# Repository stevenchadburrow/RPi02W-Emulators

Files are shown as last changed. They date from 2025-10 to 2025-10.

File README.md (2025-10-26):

# RPi02W-Emulators
<b>Running Emulators on a Raspberry Pi Zero 2W</b><br>

<b>Purpose:</b><br>
This project is to introduce myself to how the Raspberry Pi Zero 2W works, and further my knowledge on 'modern' microprocessors running Linux.  The immediate goal is to make a handheld device that plays NES, Gameboy, Gameboy Color, and Gameboy Advance games that can also connect to the television.  Additional emulators to follow.<br>

<b>Connecting an ILI9341 LCD in SPI mode using pins:</b><br>
CS = GPIO8 / Pin24<br>
MISO = GPIO9 / Pin21<br>
MOSI = GPIO10 / Pin19<br>
SCLK = GPIO11 / Pin23<br>
RESET = GPIO0 / Pin27<br>
DC = GPIO1 / Pin28<br>
LED is connected to 3V3<br>

<b>Connecting a 3.5mm Audio Jack using pins:</b><br>
LEFT = GPIO12 / Pin32<br>
RIGHT = GPIO13 / Pin33<br>

<b>Additional Requirements:</b><br>
You will also need a USB-Micro to USB-A (Female) adapter, and an HDMI-mini to HDMI adapter.<br>

<b>Instructions to Install:</b><br>
1) Re-image an 8GB+ SD Card with Raspberry Pi OS (Lite) 64-bit.<br>
2) Create user named ``` username ``` with pass named ``` password ```.<br>
3) ``` sudo raspi-config ```, change settings in Auto Login to automatically login without password required, as well as booting to Console instead of Desktop.<br>
4) ``` mkdir ~/Emulators ```, put all files found here into that folder.<br>
5) ``` mkdir ~/Emulators/ROMS ```, put whatever ROMs into that folder.  You can use sub-folders to help organize your ROMs.<br>
6) You can pull the SD Card from the Pi and connect it to another Linux computer to transfer files, use built-in Desktop environment, or some other means.<br>
7) ``` sudo nano /boot/firmware/config.txt ```, and comment out the line ``` #dtoverlay=vc4-kms-v3d ```, the then add these lines to the bottom under ``` [all] ```:
   ```
   dtoverlay=vc4-fkms-v3d
   hdmi_group=1
   hdmi_mode=1
   hdmi_drive=2
   max_framebuffers=2
   enable_tvout=0
   dtparam=spi=on
   dtoverlay=fbtft,spi0-0,ili9341,bgr,rotate=270,speed=50000000,dc_pin=1,reset_pin=0,framebuffer_width=320,framebuffer_height=240
   dtoverlay=audremap,pins_12_13
   audio_pwm_mode=2
   disable_audio_dither
   ```
8) Optionally you can also overclock the Pi by also including:
   ```
   arm_freq=1200
   over_voltage=2
   ```
9) ``` sudo nano /boot/firmware/cmdline.txt ```, then add to the end of the first line:
   ```
   video=HDMI-A-1:640x480M@60,margin_top=20,margin_bottom=20,margin_left=20,margin_right=20
   ```
10) ``` sudo nano /etc/rc.local ```, and if file already exists, just add ``` sudo modprobe snd-pcm-oss ```.  Else, add these lines to the file:
    ```
    #!/bin/sh
    sudo modprobe snd-pcm-oss
    exit 0
    ```
11) ``` sudo chmod +rwx /etc/rc.local ; sudo chown root /etc/rc.local ``` to give permissions to file.<br>
12) ``` sudo reboot ``` for changes to take effect.<br>
13) ``` cd ~/Emulators ; sh install.sh ```, to compile all C files.<br>
14) To run: ``` cd ~/Emulators ; sh run.sh ```, or to auto run on boot: ``` echo 'cd ~/Emulators/ ; sh run.sh' >> ~/.bashrc ```.<br>

<b>Features:</b><br>
- If HDMI is plugged in on boot, games will be played through HDMI.  Else, games will be played through LCD.<br>
- It can use the on-board buttons, a USB keyboard, or an Xbox360 style USB controller.<br>
- Has additional features such as fast-forward button, turbo buttons, and save/load RAM to external file.<br>
- All files here are compiled using ``` gcc ``` and only uses standard Linux libraries.<br>
- In order to draw to the screen, each emulator will write directly to ``` /dev/fb0 ```.<br>
- In order to get on-board button state, each emulator will read directly from GPIO pins using the ``` pigpio ``` library.<br>
- In order to get keyboard events, each emulator will read directly from ``` /dev/input/event0 ```.<br>
- In order to get joystick events, each emulator will read directly from ``` /dev/input/js0 ```.<br>
- In order to send audio data, each emulator will stream directly to ``` /dev/dsp ```.<br>
- Warning: ``` /dev/dsp ``` is only available after ``` sudo modprobe snd-pcm-oss ```.<br>

<b>NES, GB, and GBA Emulator Development:</b><br>
- PICnes is my own NES emulator that was previously made for the PIC32MZ, initial code found <a href="https://github.com/stevenchadburrow/AcolyteHandheld">here</a>.<br>
- PeanutGB is an MIT licensed GB/GBC emulator, found <a href="https://github.com/deltabeard/Peanut-GB">here</a>. The PeanutGB emulator used is actually a version by 'froggestspirit', found <a href="https://github.com/froggestspirit/Peanut-GB">here</a>, in order to play Gameboy Color games.<br>
- gdkGBA is a public domain GBA emulator, found <a href="https://github.com/gdkchan/gdkGBA">here</a>.  I have been altering it by copying code from a version by 'jakibaki', found <a href="https://github.com/jakibaki/gdkGBA">here</a>.  It runs well enough at 20 FPS.  I'm using Normmatt's open-source BIOS, hosted by Nebuleon <a href="https://github.com/Nebuleon/ReGBA/">here</a>.<br>

<b>Videos:</b><br>
<a href="https://youtube.com/shorts/ARCSKjPH7FA?si=rqlXaKl9zKCdxzBo">Youtube Short of me playing Tobu Tobu Girl DX</a><br>

<b>Pictures:</b><br>
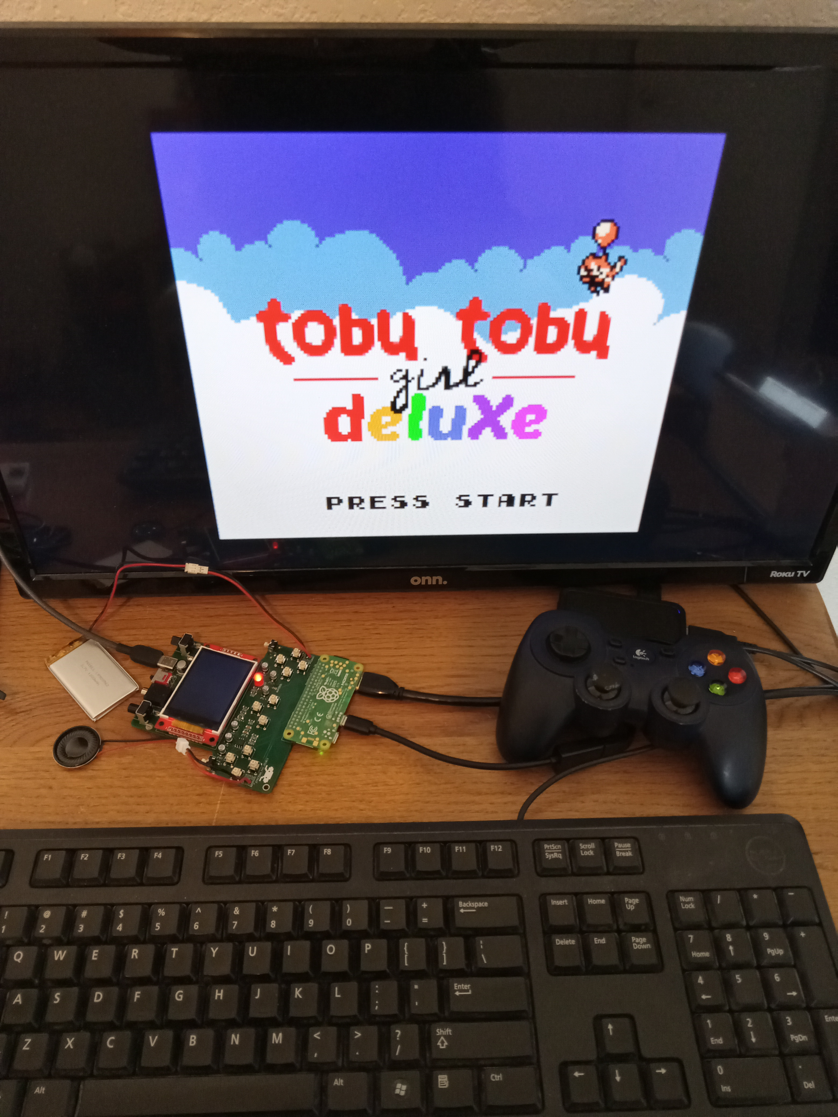
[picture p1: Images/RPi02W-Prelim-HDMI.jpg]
<br>
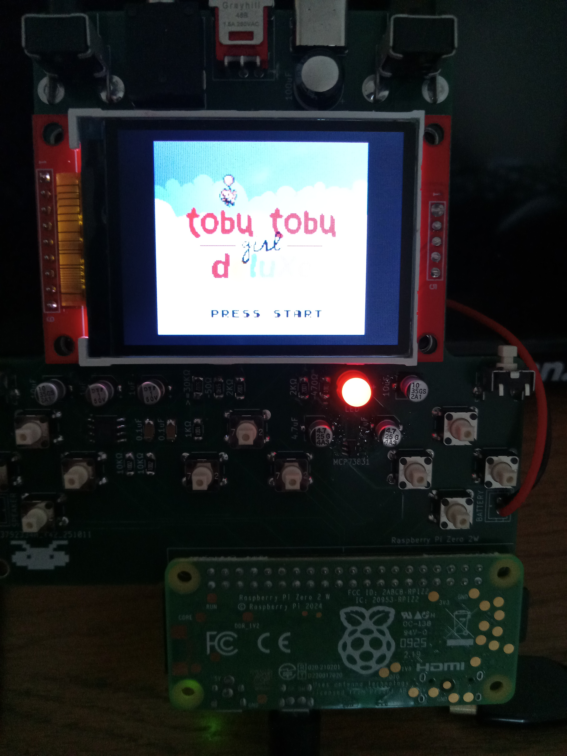
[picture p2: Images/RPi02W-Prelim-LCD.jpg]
<br>
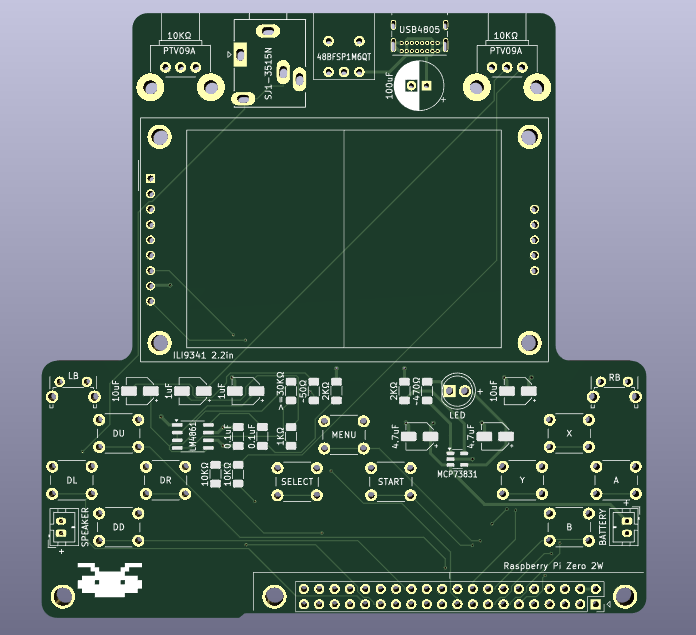
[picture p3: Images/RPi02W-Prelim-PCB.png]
<br>
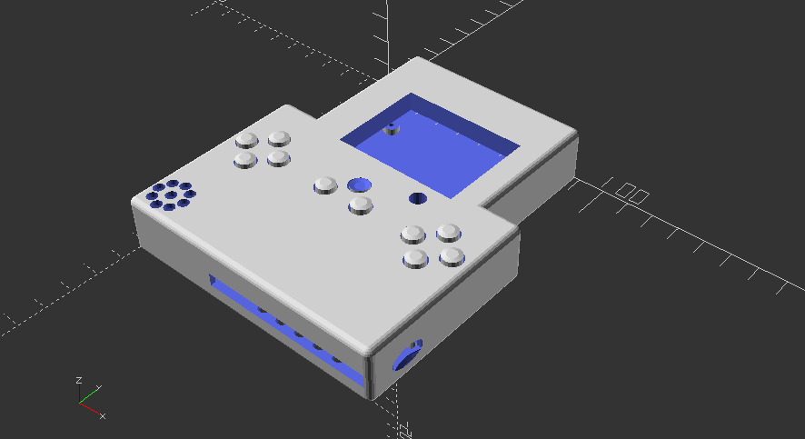
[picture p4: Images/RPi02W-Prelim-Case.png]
<br>
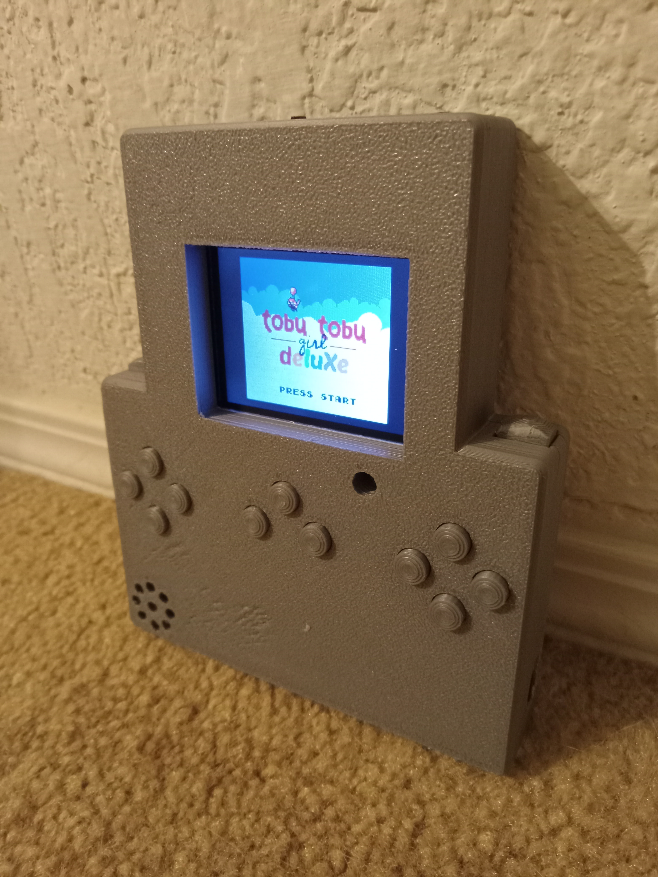
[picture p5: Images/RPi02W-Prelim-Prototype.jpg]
<br>

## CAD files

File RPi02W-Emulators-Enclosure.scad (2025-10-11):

// RPi02W-PeanutGB Enclosure



module radiusedblock(xlen,ylen,zlen,radius) {
	hull() {
		translate([radius,radius,radius]) sphere(r=radius);
		translate([xlen + radius , radius , radius]) sphere(r=radius);
		translate([radius , ylen + radius , radius]) sphere(r=radius);    
		translate([xlen + radius , ylen + radius , radius]) sphere(r=radius);
		translate([radius , radius , zlen + radius]) sphere(r=radius);
		translate([xlen + radius , radius , zlen + radius]) sphere(r=radius);
		translate([radius,ylen + radius,zlen + radius]) sphere(r=radius);
		translate([xlen + radius,ylen + radius,zlen + radius]) sphere(r=radius);
	}
}

$fn = 20; // higher detail to curves

thickness = 2.0;
gap = 0.5;
height = 15.0;
board = 5.0; // top of pcb's 

scale([1, -1, 1]) {
difference() {
union() {
	translate([15.0-gap-thickness,0.0-gap-thickness,0.0-gap-thickness])
	{
		//cube([70.0+2*gap+2*thickness,
		//	57.5+2*gap+2*thickness,
		//	height+2*gap+2*thickness]);
		radiusedblock(70.0+2*gap+2*thickness-5.0,
			55.5+2*gap+2*thickness-5.0,
			height+2*gap+2*thickness-5.0,
			2.5);
	}
	translate([0.0-gap-thickness,55.5-gap-thickness-2.0,0.0-gap-thickness])
	{
		//cube([100.0+2*gap+2*thickness,
		//	62.5+2*gap+2*thickness+2.0,
		//	height+2*gap+2*thickness]);
		radiusedblock(100.0+2*gap+2*thickness-5.0,
			64.5+2*gap+2*thickness+2.0-5.0,
			height+2*gap+2*thickness-5.0,
			2.5);
	}
}
union() {
	translate([15.0-gap,0.0-gap,0.0-gap])
	{
		cube([70.0+2*gap,55.5+2*gap,height+2*gap]);
	}
	translate([0.0-gap,55.5-gap,0.0-gap])
	{
		cube([100.0+2*gap,64.5+2*gap,height+2*gap]);
	}
} 
union() {
	// backlight pot
	translate([23.0,0.0-thickness-2,board+6.5]) {
	rotate([-90,0,0]) {
		cylinder(thickness+4, 3.5, 3.5);
	} }
	// audio jack
	translate([37.5,0.0-thickness-2,board+3.5]) {
	rotate([-90,0,0]) {
		cylinder(thickness+4, 3.5, 3.5);
	} }
	// power switch
	translate([46.0,0.0-thickness-2,board]) {
		cube([8.0,0.0+thickness+4,5.0]);
	}
	// usb port
	translate([57.5,0.0-thickness-2,board]) {
		cube([10.0,0.0+thickness+04,4.0]);
	}
	// audio pot
	translate([77.0,0.0-thickness-2,board+6.5]) {
	rotate([-90,0,0]) {
		cylinder(thickness+4, 3.5, 3.5);
	} }
	// left shoulder button
	translate([5.25,55.5,board+3.0]) {
		translate([-5.75,-thickness-gap-3,-4.0]) {
			cube([10.0,thickness+gap+4,8.0]);
		}
	}
	// right shoulder button
	translate([94.75,55.5,board+3.0]) {
		translate([-4.25,-thickness-gap-3,-4.0]) {
			cube([10.0,thickness+gap+4,8.0]);
		}
	}
	// lcd screen
	translate([23.0,18.0,height-1]) {
		cube([54.0,38.0,thickness+2]);
	}
	// pi ports
	translate([35.0,122.5-gap-thickness,board+2-5.0]) {
		cube([65.0,thickness+2*gap+2*thickness,5.0]);
	}
	// pi sdcard
	translate([100.0-1.0,100.0,board+2-3.0]) {
		cube([thickness+gap+2.0,12.5,3.0]);
		translate([6.75,6.25,1.5]) {
			scale([1,1.85,1]) {
				sphere(5.0);
			}
		}
	}
	// directional buttons
	translate([12.75,69.5,height-1]) {
		cylinder(thickness+2,4.0,4.0);
	}
	translate([12.75,85.0,height-1]) {
		cylinder(thickness+2,4.0,4.0);
	}
	translate([5.0,77.25,height-1]) {
		cylinder(thickness+2,4.0,4.0);
	}
	translate([20.5,77.25,height-1]) {
		cylinder(thickness+2,4.0,4.0);
	}
	// action buttons
	translate([87.25,69.5,height-1]) {
		cylinder(thickness+2,4.0,4.0);
	}
	translate([87.25,85.0,height-1]) {
		cylinder(thickness+2,4.0,4.0);
	}
	translate([79.5,77.25,height-1]) {
		cylinder(thickness+2,4.0,4.0);
	}
	translate([95.0,77.25,height-1]) {
		cylinder(thickness+2,4.0,4.0);
	}
	// start/select buttons
	translate([42.25,77.5,height-1]) {
		cylinder(thickness+2,4.0,4.0);
	}
	translate([57.75,77.5,height-1]) {
		cylinder(thickness+2,4.0,4.0);
	}
	// menu button
	translate([50.0,69.75,height-1]) {
		cylinder(thickness+2,4.0,4.0);
	}
	// led
	translate([68.75,62.5,height-1]) {
		cylinder(thickness+2,3.25,3.25);
	}
	// speaker holes
	translate([7.5, 112.5, height-1]) {
		cylinder(thickness+2, 2, 2);
		translate([0, -6, 0]) {
			cylinder(thickness+2, 2, 2);
		}
		translate([0, 6, 0]) {
			cylinder(thickness+2, 2, 2);
		}
		translate([-6, 0, 0]) {
			cylinder(thickness+2, 2, 2);
		}
		translate([6, 0, 0]) {
			cylinder(thickness+2, 2, 2);
		}
		translate([-6/sqrt(2), -6/sqrt(2), 0]) {
			cylinder(thickness+2, 2, 2);
		}
		translate([6/sqrt(2), -6/sqrt(2), 0]) {
			cylinder(thickness+2, 2, 2);
		}
		translate([6/sqrt(2), 6/sqrt(2), 0]) {
			cylinder(thickness+2, 2, 2);
		}
		translate([-6/sqrt(2), 6/sqrt(2), 0]) {
			cylinder(thickness+2, 2, 2);
		}
	}
	// screw holes
	translate([19.5,20.5,-gap-thickness]) {
		cylinder(gap+thickness,3.5,1.5);
	}
	translate([80.75,20.5,-gap-thickness]) {
		cylinder(gap+thickness,3.5,1.5);
	}
	translate([19.5,54.5,-gap-thickness]) {
		cylinder(gap+thickness,3.5,1.5);
	}
	translate([80.75,54.5,-gap-thickness]) {
		cylinder(gap+thickness,3.5,1.5);
	}
	translate([3.5,96.5,-gap-thickness]) {
		cylinder(gap+thickness,3.5,1.5);
	}
	//translate([38.5,96.5,-gap-thickness]) {
	//	cylinder(gap+thickness,3.5,1.5);
	//}
	translate([96.5,96.5,-gap-thickness]) {
		cylinder(gap+thickness,3.5,1.5);
	}
	// ventilation holes
	//translate([43.5,100.0,-thickness-gap-1]) {
	//	cylinder(gap+thickness+1,2.0,2.0);
	//	translate([0.0,8.0,0.0]) {
	//		cylinder(gap+thickness+1,2.0,2.0);
	//	}
	//	translate([0.0,16.0,0.0]) {
	//		cylinder(gap+thickness+1,2.0,2.0);
	//	}
	//}
	translate([43.5+8.0,100.0,-thickness-gap-1]) {
		cylinder(gap+thickness+1,2.0,2.0);
		translate([0.0,8.0,0.0]) {
			cylinder(gap+thickness+1,2.0,2.0);
		}
		translate([0.0,16.0,0.0]) {
			cylinder(gap+thickness+1,2.0,2.0);
		}
	}
	translate([43.5+16.0,100.0,-thickness-gap-1]) {
		cylinder(gap+thickness+1,2.0,2.0);
		translate([0.0,8.0,0.0]) {
			cylinder(gap+thickness+1,2.0,2.0);
		}
		translate([0.0,16.0,0.0]) {
			cylinder(gap+thickness+1,2.0,2.0);
		}
	}
	translate([43.5+24.0,100.0,-thickness-gap-1]) {
		cylinder(gap+thickness+1,2.0,2.0);
		translate([0.0,8.0,0.0]) {
			cylinder(gap+thickness+1,2.0,2.0);
		}
		translate([0.0,16.0,0.0]) {
			cylinder(gap+thickness+1,2.0,2.0);
		}
	}
	translate([43.5+32.0,100.0,-thickness-gap-1]) {
		cylinder(gap+thickness+1,2.0,2.0);
		translate([0.0,8.0,0.0]) {
			cylinder(gap+thickness+1,2.0,2.0);
		}
		translate([0.0,16.0,0.0]) {
			cylinder(gap+thickness+1,2.0,2.0);
		}
	}
	translate([43.5+40.0,100.0,-thickness-gap-1]) {
		cylinder(gap+thickness+1,2.0,2.0);
		translate([0.0,8.0,0.0]) {
			cylinder(gap+thickness+1,2.0,2.0);
		}
		translate([0.0,16.0,0.0]) {
			cylinder(gap+thickness+1,2.0,2.0);
		}
	}
	//translate([43.5+48.0,100.0,-thickness-gap-1]) {
	//	cylinder(gap+thickness+1,2.0,2.0);
	//	translate([0.0,8.0,0.0]) {
	//		cylinder(gap+thickness+1,2.0,2.0);
	//	}
	//	translate([0.0,16.0,0.0]) {
	//		cylinder(gap+thickness+1,2.0,2.0);
	//	}
	//}
}

// uncomment to show top half
translate([-10.0,-10.0,-100.0]) {
	//cube([120.0,210.0,100.0+board]);
}
// uncomment to show bottom half
translate([-10.0,-10.0,board]) {
	//cube([120.0,210.0,100.0]);
}

} }
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

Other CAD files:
RPi02W-Enclosure.scad

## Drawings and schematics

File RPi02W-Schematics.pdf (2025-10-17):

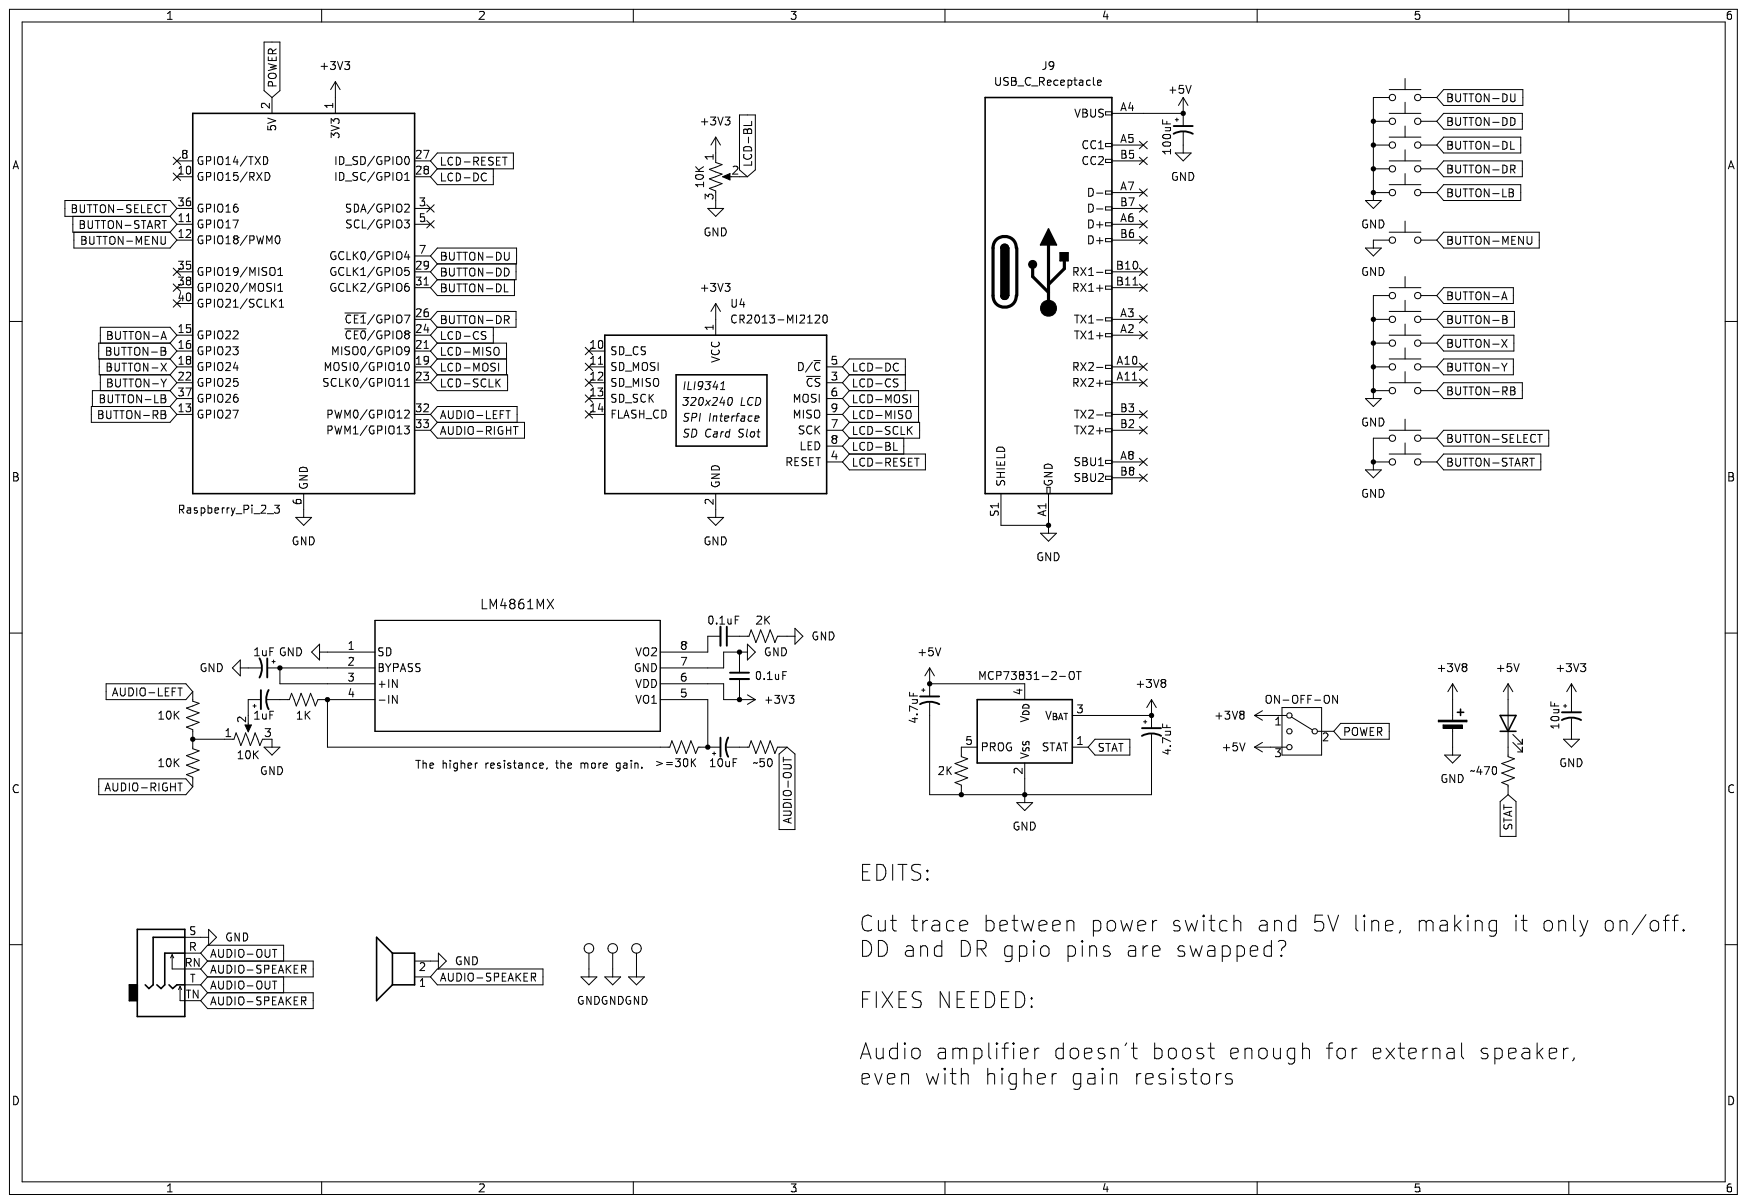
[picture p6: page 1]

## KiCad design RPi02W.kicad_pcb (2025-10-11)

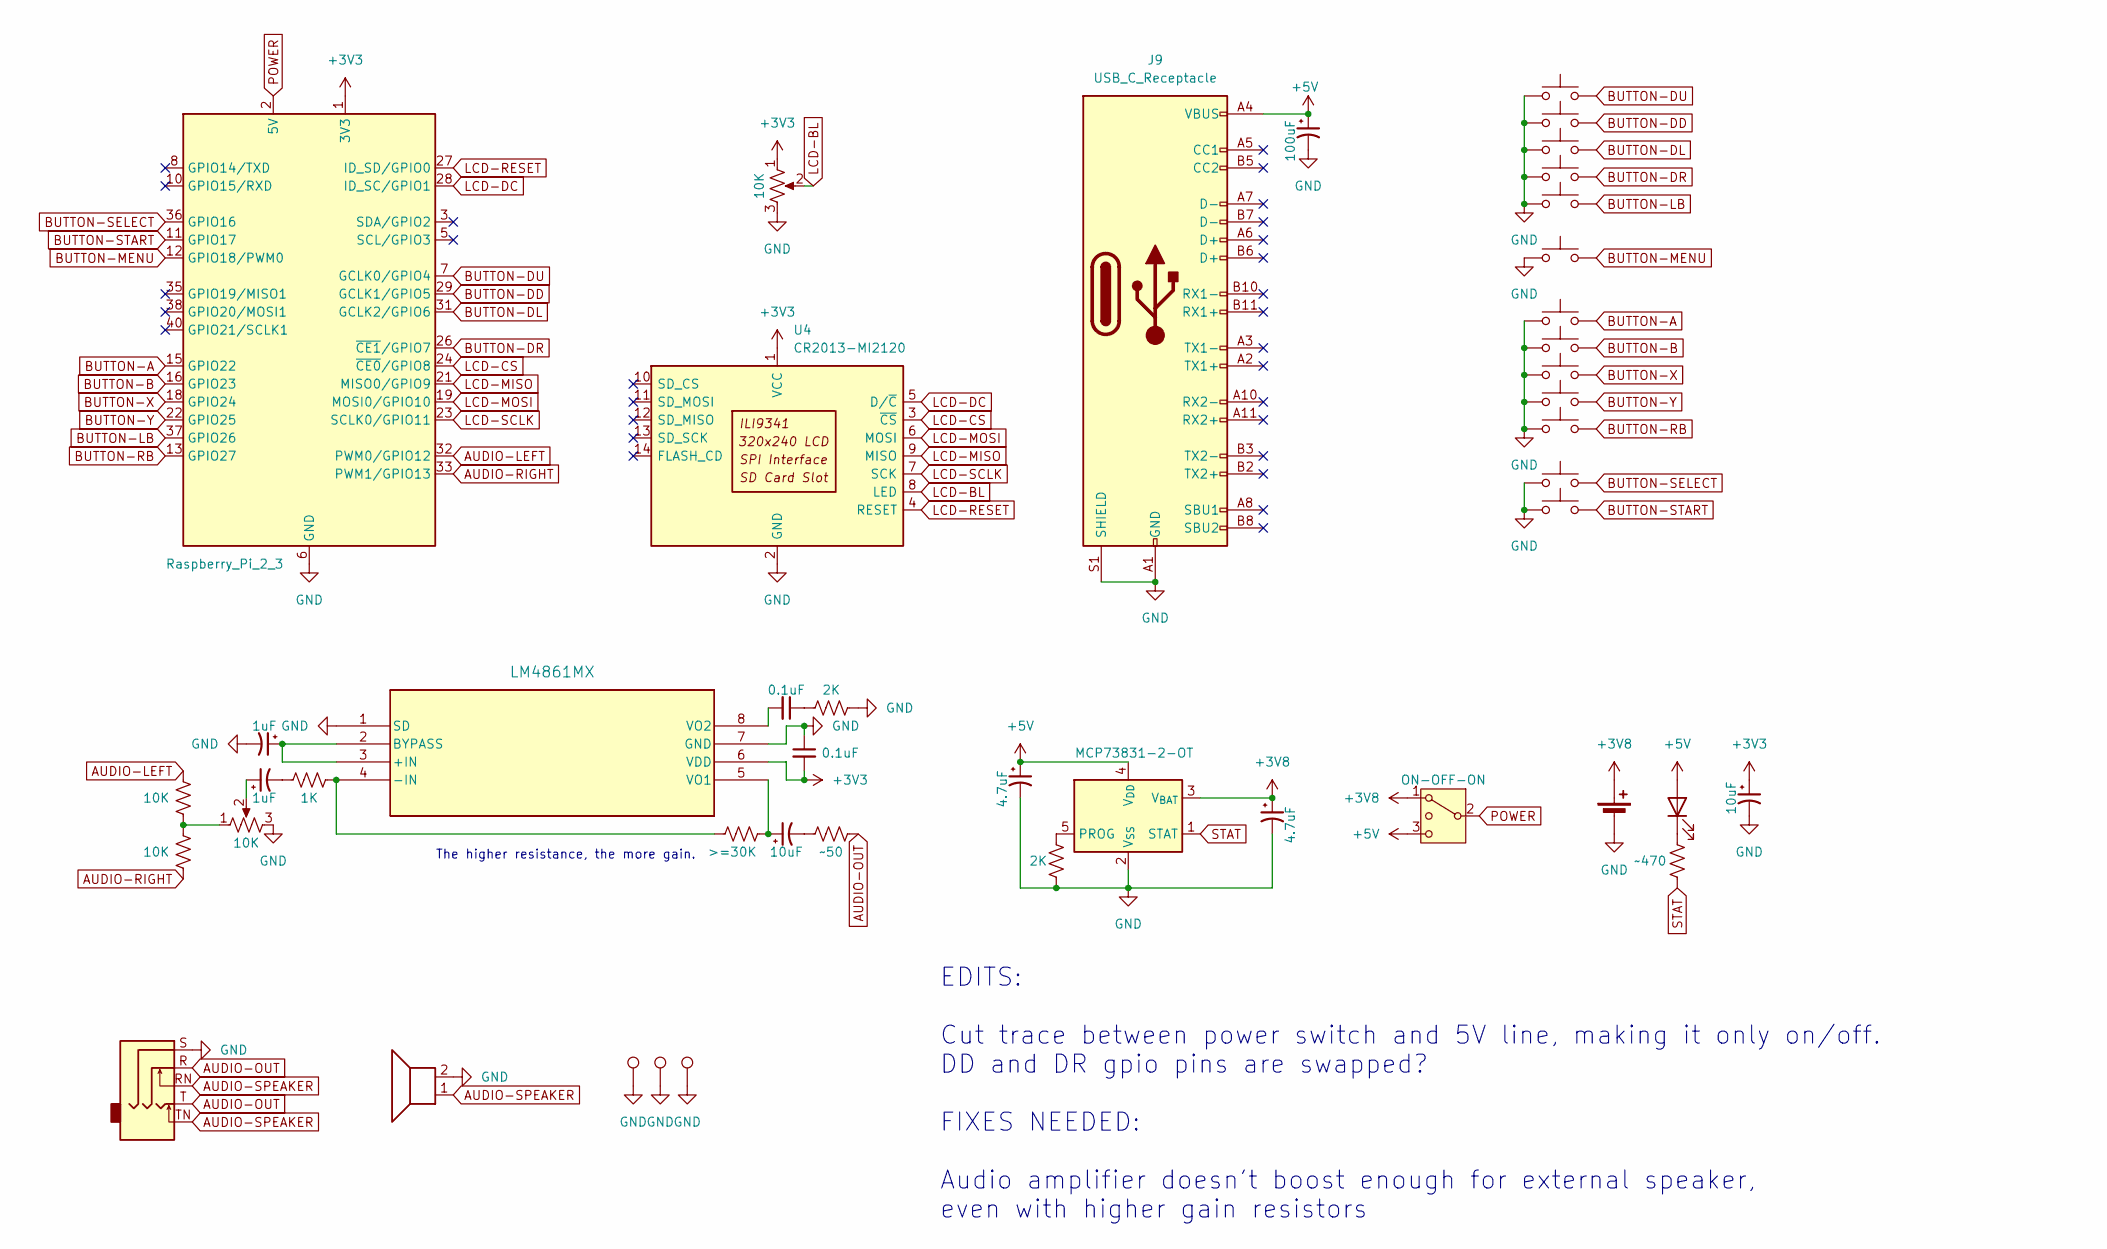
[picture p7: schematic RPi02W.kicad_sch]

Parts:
BT1: Battery_Cell; JST_PH_B2B-PH-K_1x02_P2.00mm_Vertical
C1, C2, C3, C4, C5, C9: C_Polarized_Small_US; CP_Elec_4x5.8
C6, C7: C_Small; C_1206_3216Metric_Pad1.33x1.80mm_HandSolder
C8: C_Polarized_Small_US; CP_Radial_D8.0mm_P2.50mm
D1: LED; LED_Custom_D5.0mm
J1: Raspberry_Pi_2_3; PinHeader_2x20_P2.54mm_Vertical
J3: AudioJack3_SwitchTR; Jack_3.5mm_Ledino_Edited_KB3SPRS_Horizontal
J9: USB_C_Receptacle; USB_C_Receptacle_GCT_USB4085
LS1: Speaker; JST_PH_B2B-PH-K_1x02_P2.00mm_Vertical
R1, R2, R3, R4, R5, R6, R7, R8: R_US; R_1206_3216Metric_Pad1.30x1.75mm_HandSolder
RV2, RV3: R_Potentiometer_US; Potentiometer_Bourns_PTV09A-2_Single_Horizontal
SW1: SW_SPDT_MSM; 48BFSP1M6QT
SW2, SW3, SW4, SW5, SW6, SW7, SW8, SW9, SW12, SW13, SW14: SW_Push; SW_PUSH_6mm
SW10, SW11: SW_Push; SW_Tactile_SPST_Angled_PTS645Vx83-2LFS
TP1, TP2, TP3: TestPoint; ScrewHole-RPiZero
U1: MCP73831-2-OT; SOT-23-5
U3: LM4861MX; SO-8_3.9x4.9mm_P1.27mm
U4: CR2013-MI2120

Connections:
+3V3: C6.2, C9.1, J1.1 (3V3), J1.17 (3V3), RV3.1, U3.6 (VDD), U4.1 (VCC)
+3V8: BT1.1 (+), C2.1, SW1.1, U1.3 (V_{BAT})
+5V: C1.1, C8.1, D1.2 (A), J9.A4 (VBUS), J9.A9 (VBUS), J9.B4 (VBUS), J9.B9 (VBUS), SW1.3 (4), U1.4 (V_{DD})
AUDIO-LEFT: J1.32 (PWM0/GPIO12), R3.1
AUDIO-OUT: J3.R, J3.T, R7.1
AUDIO-RIGHT: J1.33 (PWM1/GPIO13), R4.2
AUDIO-SPEAKER: J3.RN, J3.TN, LS1.1
BUTTON-A: J1.15 (GPIO22), SW6.2
BUTTON-B: J1.16 (GPIO23), SW7.2
BUTTON-DD: J1.29 (GCLK1/GPIO5), SW3.2
BUTTON-DL: J1.31 (GCLK2/GPIO6), SW4.2
BUTTON-DR: J1.26 (~CE1/GPIO7), SW5.2
BUTTON-DU: J1.7 (GCLK0/GPIO4), SW2.2
BUTTON-LB: J1.37 (GPIO26), SW10.2
BUTTON-MENU: J1.12 (GPIO18/PWM0), SW14.2
BUTTON-RB: J1.13 (GPIO27), SW11.2
BUTTON-SELECT: J1.36 (GPIO16), SW12.2
BUTTON-START: J1.11 (GPIO17), SW13.2
BUTTON-X: J1.18 (GPIO24), SW8.2
BUTTON-Y: J1.22 (GPIO25), SW9.2
GND: BT1.2 (-), C1.2, C2.2, C4.2, C6.1, C8.2, C9.2, J1.6 (GND), J1.9 (GND), J1.14 (GND), J1.20 (GND), J1.25 (GND), J1.30 (GND), J1.34 (GND), J1.39 (GND), J3.S, J9.A1 (GND), J9.A12 (GND), J9.B1 (GND), J9.B12 (GND), J9.S1 (SHIELD), LS1.2, R1.2, R8.1, RV2.3, RV3.3, SW2.1, SW3.1, SW4.1, SW5.1, SW6.1, SW7.1, SW8.1, SW9.1, SW10.1, SW11.1, SW12.1, SW13.1, SW14.1, TP1.1, TP2.1, TP3.1, U1.2 (V_{SS}), U3.1 (SD), U3.7 (GND), U4.2 (GND)
LCD-BL: RV3.2, U4.8 (LED)
LCD-CS: J1.24 (~CE0/GPIO8), U4.3 (~CS)
LCD-DC: J1.28 (ID_SC/GPIO1), U4.5 (D/~C)
LCD-MISO: J1.21 (MISO0/GPIO9), U4.9 (MISO)
LCD-MOSI: J1.19 (MOSI0/GPIO10), U4.6 (MOSI)
LCD-RESET: J1.27 (ID_SD/GPIO0), U4.4 (RESET)
LCD-SCLK: J1.23 (SCLK0/GPIO11), U4.7 (SCK)
unnamed: C3.1, RV2.2
unnamed: C3.2, R5.2
unnamed: C5.2, R7.2
unnamed: C7.1, R8.2
unnamed: D1.1 (K), R2.1
unnamed: R3.2, R4.1, RV2.1
unnamed: R1.1, U1.5 (PROG)
unnamed: C4.1, U3.2 (BYPASS), U3.3 (+IN)
unnamed: R5.1, R6.2, U3.4 (-IN)
unnamed: C5.1, R6.1, U3.5 (VO1)
unnamed: C7.2, U3.8 (VO2)
POWER: J1.2 (5V), J1.4 (5V), SW1.2 (3)
STAT: R2.2, U1.1 (STAT)

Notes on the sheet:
The higher resistance, the more gain.
EDITS: Cut trace between power switch and 5V line, making it only on/off. DD and DR gpio pins are swapped? FIXES NEEDED: Audio amplifier doesn't boost enough for external speaker, even with higher gain resistors

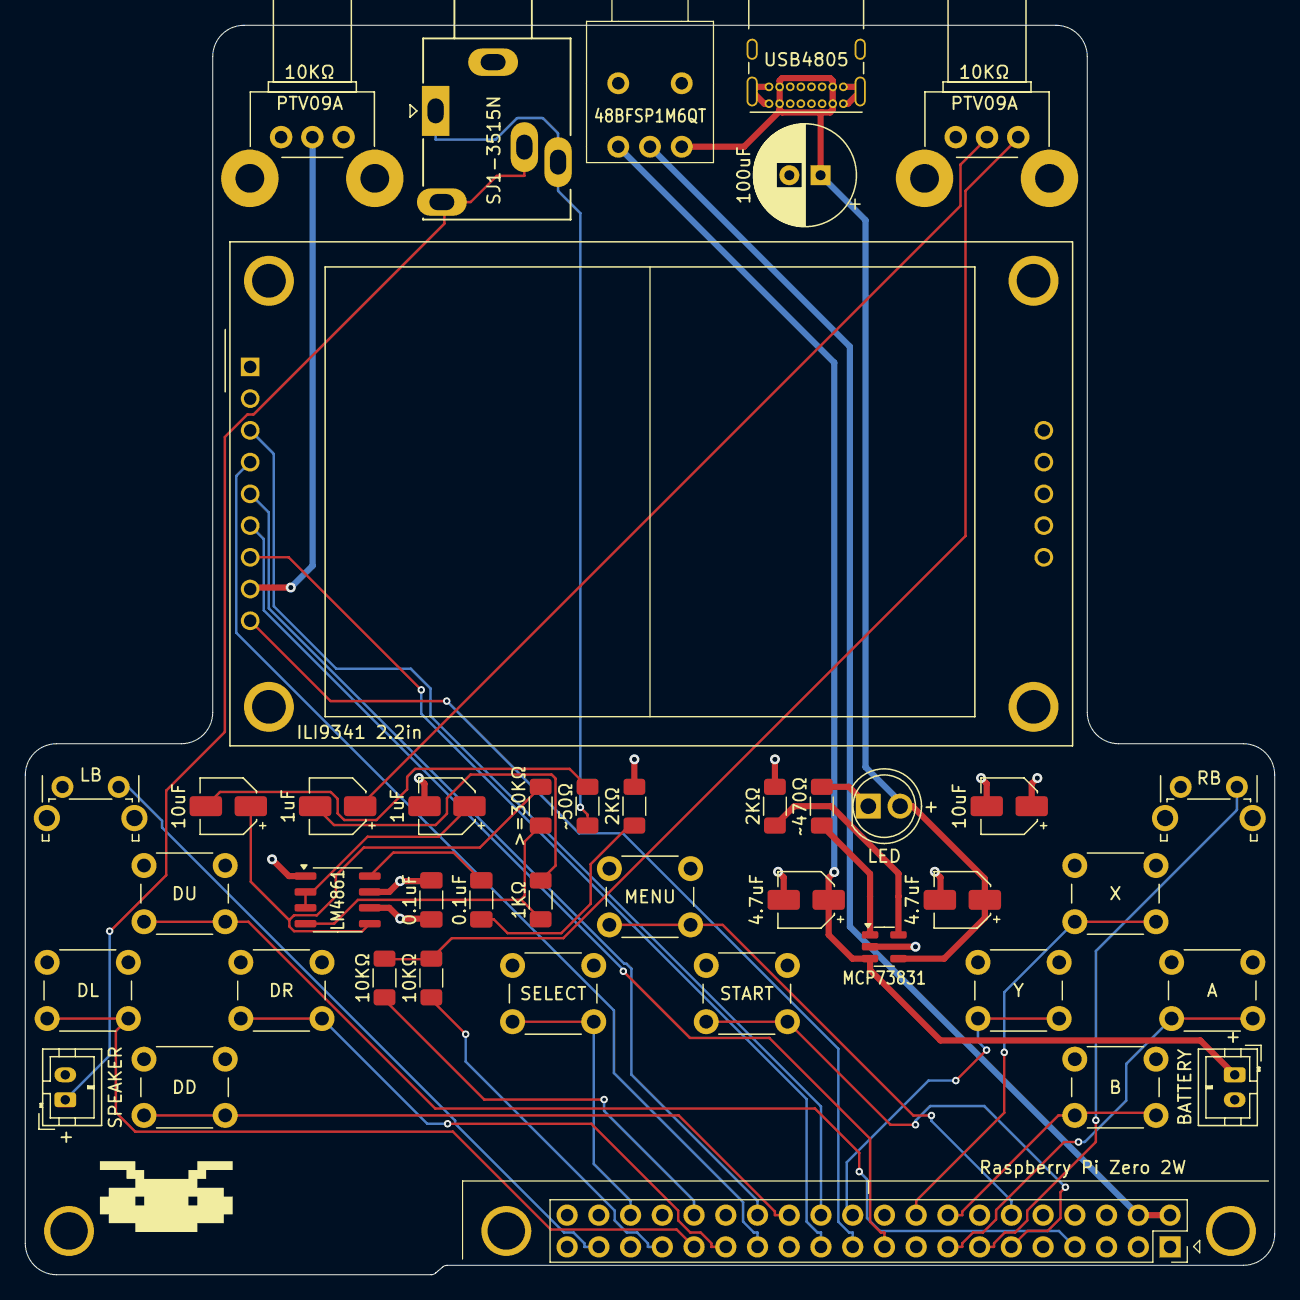
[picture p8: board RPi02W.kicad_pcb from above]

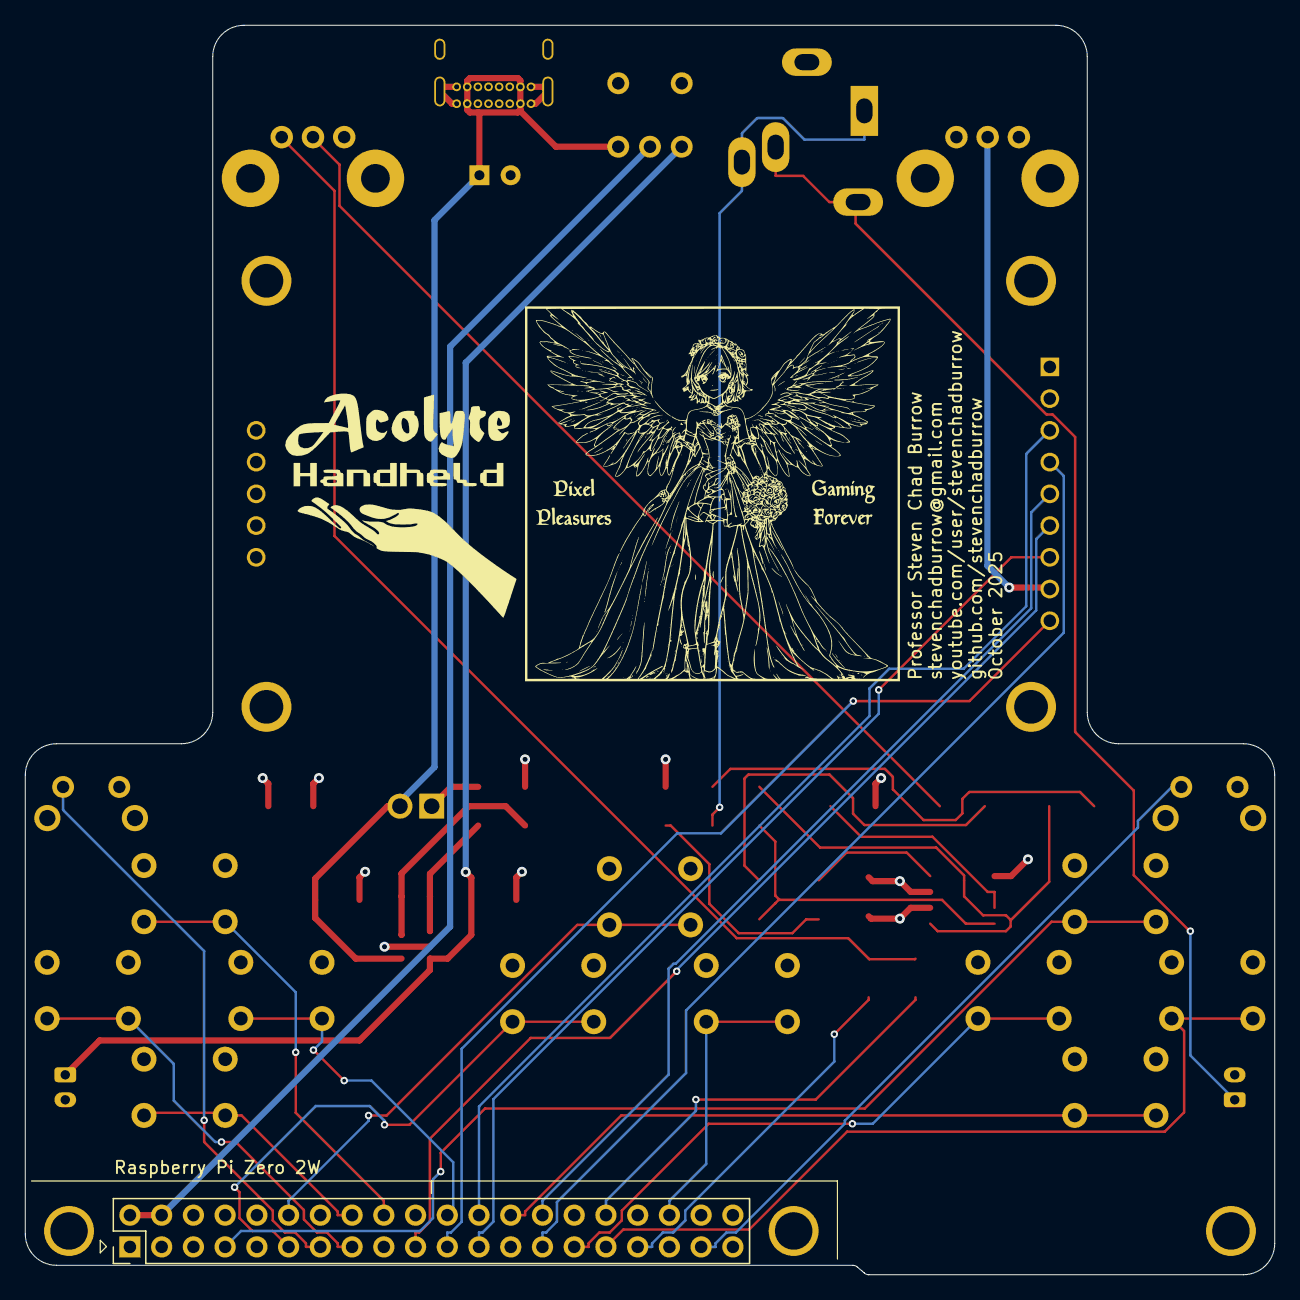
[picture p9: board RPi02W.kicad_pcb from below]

Board: 4 copper layers, 100.0 x 100.0 mm, 50 parts (5 on the bottom side), 41 nets.

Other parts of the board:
G100: LOGO; Angel
G101: LOGO; Acolyte
G102: LOGO; Handheld
G103: LOGO; Hand
G109: LOGO; Alien

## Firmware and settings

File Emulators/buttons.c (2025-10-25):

#include <stdio.h>
#include <fcntl.h>
#include <stdlib.h>
#include <unistd.h>
#include <pigpio.h>

// must compile with:  -lpigpio

#define LOOPS 3

int main()
{
	system("echo \"0000000000000\" > buttons1.val");
	system("echo \"0000000000000\" > buttons2.val");

	char button[13];

	for (int i=0; i<13; i++) button[i] = '0';

	char string[256];

	for (int i=0; i<256; i++) string[i] = 0;

    if (gpioInitialise() == PI_INIT_FAILED)
	{
        printf("ERROR: Failed to initialize the GPIO interface.\n");
        return 0;
    }

	//gpioCfgInterfaces(PI_DISABLE_FIFO_IF | PI_DISABLE_SOCK_IF | PI_LOCALHOST_SOCK_IF); // stops popup messages?

	gpioSetMode(4, PI_INPUT); // du
	gpioSetPullUpDown(4, PI_PUD_UP);
	gpioSetMode(5, PI_INPUT); // dr?
	gpioSetPullUpDown(5, PI_PUD_UP);
	gpioSetMode(6, PI_INPUT); // dl
	gpioSetPullUpDown(6, PI_PUD_UP);
	gpioSetMode(7, PI_INPUT); // dd?
	gpioSetPullUpDown(7, PI_PUD_UP);

	gpioSetMode(22, PI_INPUT); // a
	gpioSetPullUpDown(22, PI_PUD_UP);
	gpioSetMode(23, PI_INPUT); // b
	gpioSetPullUpDown(23, PI_PUD_UP);
	gpioSetMode(24, PI_INPUT); // x
	gpioSetPullUpDown(24, PI_PUD_UP);
	gpioSetMode(25, PI_INPUT); // y
	gpioSetPullUpDown(25, PI_PUD_UP);

	gpioSetMode(26, PI_INPUT); // lb
	gpioSetPullUpDown(26, PI_PUD_UP);
	gpioSetMode(27, PI_INPUT); // rb
	gpioSetPullUpDown(27, PI_PUD_UP);

    gpioSetMode(16, PI_INPUT); // select
	gpioSetPullUpDown(16, PI_PUD_UP);
	gpioSetMode(17, PI_INPUT); // start
	gpioSetPullUpDown(17, PI_PUD_UP);
	gpioSetMode(18, PI_INPUT); // menu
	gpioSetPullUpDown(18, PI_PUD_UP);

	int swap = 1;

	while (1)
	{
		for (int i=0; i<13; i++) button[i] = '0';

		for (int i=0; i<LOOPS; i++)
		{
			if (gpioRead(18) == 0) // menu
			{
				button[0] = '1';
			}

			if (gpioRead(4) == 0) // du
			{
				button[1] = '1';
			}

			if (gpioRead(7) == 0) // dr?
			{
				button[2] = '1';
			}

			if (gpioRead(6) == 0) // dl
			{
				button[3] = '1';
			}

			if (gpioRead(5) == 0) // dd?
			{
				button[4] = '1';
			}

			if (gpioRead(16) == 0) // select
			{
				button[5] = '1';
			}

			if (gpioRead(17) == 0) // start
			{
				button[6] = '1';
			}

			if (gpioRead(22) == 0) // a
			{
				button[7] = '1';
			}

			if (gpioRead(23) == 0) // b
			{
				button[8] = '1';
			}

			if (gpioRead(24) == 0) // x
			{
				button[9] = '1';
			}

			if (gpioRead(25) == 0) // y
			{
				button[10] = '1';
			}

			if (gpioRead(26) == 0) // lb
			{
				button[11] = '1';
			}

			if (gpioRead(27) == 0) // rb
			{
				button[12] = '1';
			}
		}

		for (int i=0; i<256; i++) string[i] = 0;

		sprintf(string, "echo \"%c%c%c%c%c%c%c%c%c%c%c%c%c\" > buttons%d.val",
			button[0], button[1], button[2], button[3],
			button[4], button[5], button[6], button[7], button[8],
			button[9], button[10], button[11], button[12], swap);

		//printf("%s\n", string);
		system(string);
		
		if (swap == 1) swap = 2;
		else swap = 1;

		//if (button[0] != '0') break;
	}

	gpioTerminate();

    return 0;
}
